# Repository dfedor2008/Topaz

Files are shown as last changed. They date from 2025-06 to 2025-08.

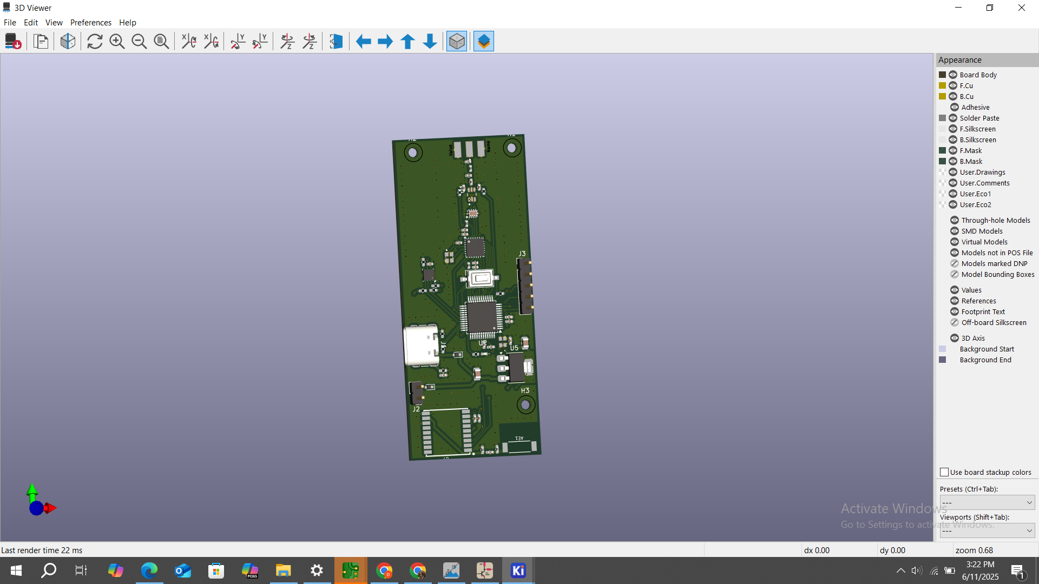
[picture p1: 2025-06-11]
3D_Image.png

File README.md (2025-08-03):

# Topaz - A Lightweight Long-Range GPS Telemetry System

---

## What is Topaz?

Topaz is a compact, cost-effective GPS telemetry platform designed for long-range data transmission using LoRa modulation. It supports both Morse code and binary telemetry formats and integrates environmental sensing, making it suitable for high-altitude ballooning, rocket recovery, remote monitoring, and more.

Topaz In Action

---

## Features & Components

- **Microcontroller** — [ATSAMD21G18A](https://www.microchip.com/en-us/product/atsamd21g18): A reliable, low-power Cortex-M0+ MCU from Microchip.
- **LoRa Radio** — [SX1262](https://www.semtech.com/products/wireless-rf/lora-transceivers/sx1262): Sub-GHz long-range radio for Morse or telemetry data.
- **GPS Receiver** — [ATGM336H](https://jlcpcb.com/partdetail/Zhongkewei-ATGM336H5N31/C90770): Provides position and timing data.
- **Environmental Sensor** — [BME280](https://www.bosch-sensortec.com/products/environmental-sensors/humidity-sensors-bme280/): Measures temperature, humidity, and pressure.
- **Power Supply** — Designed to run from USB or external LiPo/boosted AA battery (3.3V).

---

---

## Use Cases

- Tracker for rockets
- Tracking for general uses
- Environmental monitoring (bme sensor)  

---

## How It Works

1. The **ATGM336H GPS module** gathers location and time.  
2. The **BME280** reads environmental parameters.  
3. The **SAMD21** processes the data.  
4. The **SX1262** transmits the payload via LoRa (in Morse or binary formats).  
5. A paired Topaz device or SDR can receive and decode the transmission.

All firmware is written in **C++**

---

## Hardware Setup Guide

1. **Solder the PCB** — A reflow plate is recommended for clean results.  
2. **Inspect for Shorts** — Pay extra attention around power and MCU pins.  
3. **Power Up via External Supply (not USB)** — Watch for smoke or abnormal heat. Power off immediately if detected.  
4. **Connect via USB** — Once verified safe, plug into your computer.

> After soldering and testing, upload the firmware via Arduino IDE. Topaz is optimized for affordability and robustness.

---

## PCB Diagrams

### Schematic

Topaz Schematic

### Layout

Topaz Layout

---

## Software & Configuration

This project uses the Arduino platform. Libraries include:

- TinyGPS++  
- Adafruit_BME280  
- RadioHead or LoRa drivers for SX1262

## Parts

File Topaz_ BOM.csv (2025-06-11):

null | Sourced | Placed | References | Value | Footprint | Quantity
1 | ✓ | ✓ | C7, C12, C13 | 1nF | C_0402_1005Metric | 3
2 | ✓ | ✓ | C2, C22 | 100nF | C_0402_1005Metric_Pad0.74x0.62mm_HandSolder | 2
3 |  |  | C3, C5 | 100 nF | C_0402_1005Metric_Pad0.74x0.62mm_HandSolder | 2
4 | ✓ | ✓ | C10, C11 | 47pF | C_0402_1005Metric | 2
5 |  |  | C15, C16 | 3.3pF | C_0402_1005Metric | 2
6 | ✓ | ✓ | C17, C18 | 22u | C_0805_2012Metric | 2
7 |  |  | C1 | 1uF | C_0402_1005Metric_Pad0.74x0.62mm_HandSolder | 1
8 |  |  | C4 | 10 uF | C_0402_1005Metric_Pad0.74x0.62mm_HandSolder | 1
9 | ✓ | ✓ | C6 | 4.7 nF | C_0402_1005Metric_Pad0.74x0.62mm_HandSolder | 1
10 |  |  | C8 | 100nF | C_0402_1005Metric | 1
11 | ✓ | ✓ | C9 | 470nF | C_0402_1005Metric | 1
12 | ✓ | ✓ | C14 | 39pF | C_0402_1005Metric | 1
13 | ✓ | ✓ | C19 | 1uF | C_0402_1005Metric | 1
14 | ✓ | ✓ | C20 | 1.5pF | C_0402_1005Metric_Pad0.74x0.62mm_HandSolder | 1
15 | ✓ | ✓ | C21 | 10uF | C_0402_1005Metric_Pad0.74x0.62mm_HandSolder | 1
16 | ✓ | ✓ | R1, R2 | 1.8k | R_0402_1005Metric_Pad0.72x0.64mm_HandSolder | 2
17 | ✓ | ✓ | R5, R6 | 5k1 | R_0402_1005Metric_Pad0.72x0.64mm_HandSolder | 2
18 |  |  | R7, R8 | 10k | R_0402_1005Metric_Pad0.72x0.64mm_HandSolder | 2
19 | ✓ | ✓ | R9, R11 | 100 | R_0402_1005Metric | 2
20 | ✓ | ✓ | R3 | 220 | R_0402_1005Metric_Pad0.72x0.64mm_HandSolder | 1
21 |  |  | R4 | 1M | R_0402_1005Metric_Pad0.72x0.64mm_HandSolder | 1
22 | ✓ | ✓ | R10 | 300 | R_0402_1005Metric | 1
23 | ✓ | ✓ | L4, L5 | 3.9 nH | L_0402_1005Metric_Pad0.77x0.64mm_HandSolder | 2
24 | ✓ | ✓ | L1 | 15uH | L_0402_1005Metric | 1
25 | ✓ | ✓ | L2 | 47nH | L_0402_1005Metric | 1
26 | ✓ | ✓ | L3 | 9.1nH | L_0402_1005Metric | 1
27 |  |  | D1, D2 | 1N4148WT | D_SOD-523 | 2
28 | ✓ | ✓ | D3 | LED | LED_0402_1005Metric | 1
29 | ✓ | ✓ | U1 | PE4259 | PE4259 | 1
30 | ✓ | ✓ | U2 | ATSAMD21G18A-A | TQFP-48_7x7mm_P0.5mm | 1
31 | ✓ | ✓ | U3 | ECS-327TXO-2012 | OSC_ECS-327TXO-2012-33-TR | 1
32 | ✓ | ✓ | U4 | SX1262IMLTRT | QFN-24-1EP_4x4mm_P0.5mm_EP2.6x2.6mm | 1
33 |  |  | U5 | AMS1117-3.3 | SOT-223-3_TabPin2 | 1
34 | ✓ | ✓ | U6 | BME280 | Bosch_LGA-8_2.5x2.5mm_P0.65mm_ClockwisePinNumbering | 1
35 | ✓ | ✓ | U7 | ATGM336H | ATGM336H | 1
36 | ✓ | ✓ | Y1 | FA-128_32.0000MF20X-K5 | OSCCC200X160X50 | 1
37 | ✓ | ✓ | SW1 | RST | SW_Tactile_SPST_NO_Straight_CK_PTS636Sx25SMTRLFS | 1
38 | ✓ | ✓ | AE1 | 1575AT43A0040 | 609-1575AT43A0040E | 1
39 | ✓ | ✓ | FL1 | 0900FM15K0039 | Balun_Johanson_0900FM15K0039 | 1
40 | ✓ | ✓ | Je2 | Conn_Coaxial | RFSOLUTIONS_CON-SMA-EDGE-S | 1
41 | ✓ | ✓ | J1 | USBC | USB_C_Receptacle_GCT_USB4105-xx-A_16P_TopMnt_Horizontal | 1
42 |  |  | J2 | POWER IN | PinHeader_1x02_P2.54mm_Vertical | 1
43 | ✓ | ✓ | J3 | ~ | PinHeader_1x05_P2.54mm_Vertical | 1

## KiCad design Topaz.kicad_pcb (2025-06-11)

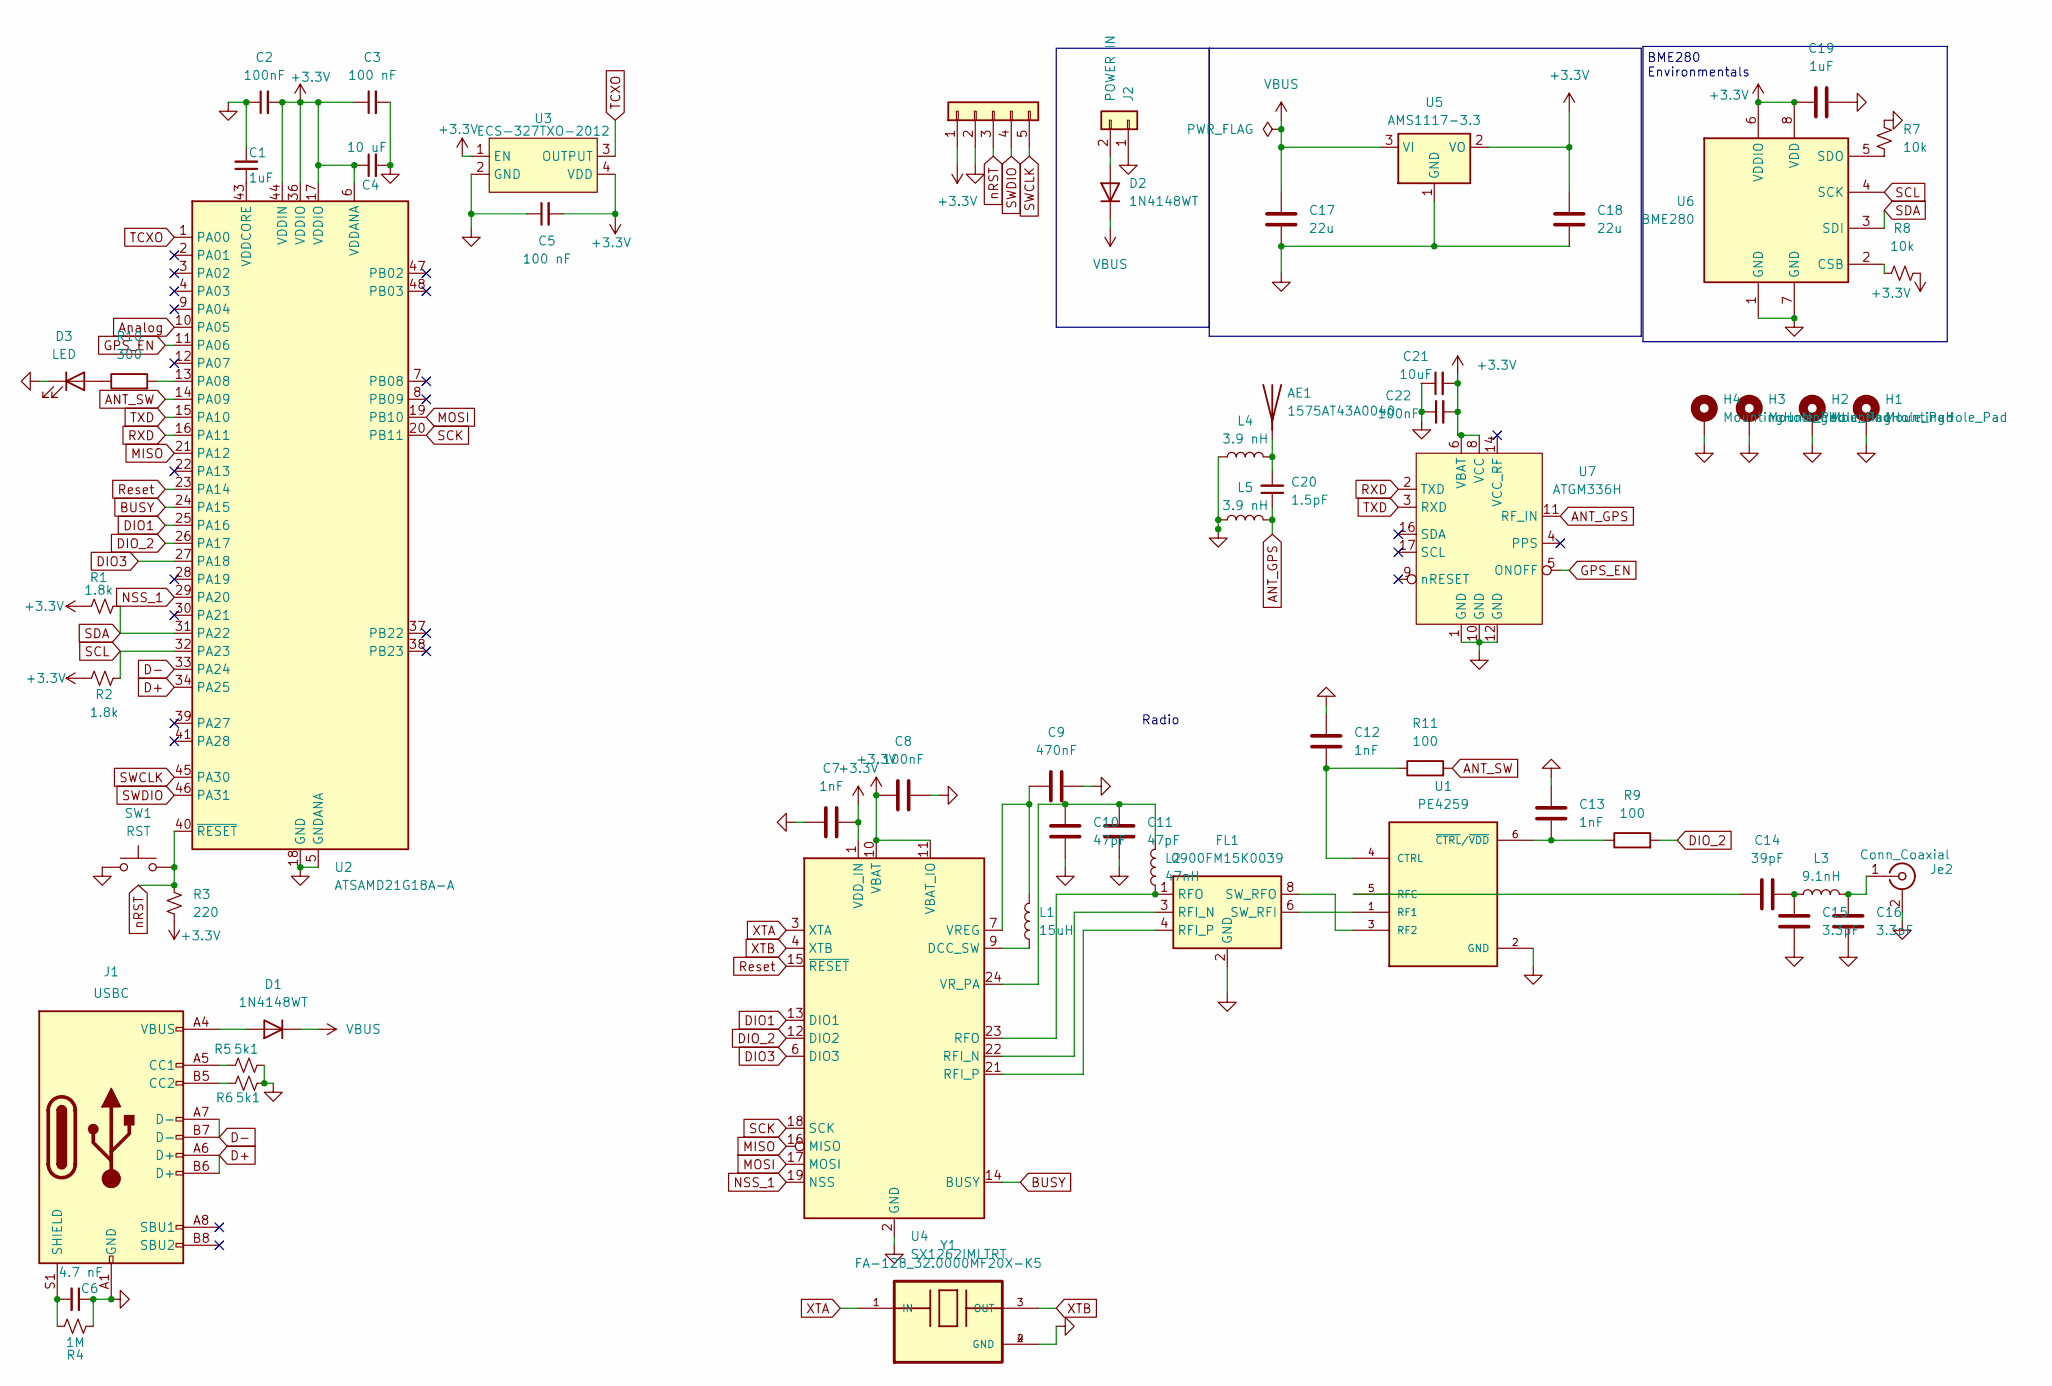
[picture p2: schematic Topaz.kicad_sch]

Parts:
AE1: 1575AT43A0040; 609-1575AT43A0040E; LCSC C239243
C1: 1uF; C_0402_1005Metric_Pad0.74x0.62mm_HandSolder; LCSC C52923
C2, C22: 100nF; C_0402_1005Metric_Pad0.74x0.62mm_HandSolder; LCSC C1525
C3, C5: 100 nF; C_0402_1005Metric_Pad0.74x0.62mm_HandSolder; LCSC C1525
C4: 10 uF; C_0402_1005Metric_Pad0.74x0.62mm_HandSolder; LCSC C19702
C6: 4.7 nF; C_0402_1005Metric_Pad0.74x0.62mm_HandSolder; LCSC C1744
C7, C12, C13: 1nF; C_0402_1005Metric
C8: 100nF; C_0402_1005Metric
C9: 470nF; C_0402_1005Metric
C10, C11: 47pF; C_0402_1005Metric
C14: 39pF; C_0402_1005Metric
C15, C16: 3.3pF; C_0402_1005Metric
C17, C18: 22u; C_0805_2012Metric
C19: 1uF; C_0402_1005Metric
C20: 1.5pF; C_0402_1005Metric_Pad0.74x0.62mm_HandSolder; LCSC C1525
C21: 10uF; C_0402_1005Metric_Pad0.74x0.62mm_HandSolder; LCSC C19702
D1, D2: 1N4148WT; D_SOD-523
D3: LED; LED_0402_1005Metric
FL1: 0900FM15K0039; Balun_Johanson_0900FM15K0039
H1, H2, H3, H4: MountingHole_Pad; MountingHole_2.1mm
J1: USBC; USB_C_Receptacle_GCT_USB4105-xx-A_16P_TopMnt_Horizontal; LCSC C136423
J2: POWER IN; PinHeader_1x02_P2.54mm_Vertical
J3: PinHeader_1x05_P2.54mm_Vertical
Je2: Conn_Coaxial; RFSOLUTIONS_CON-SMA-EDGE-S
L1: 15uH; L_0402_1005Metric
L2: 47nH; L_0402_1005Metric
L3: 9.1nH; L_0402_1005Metric
L4, L5: 3.9 nH; L_0402_1005Metric_Pad0.77x0.64mm_HandSolder; LCSC C307609
R1, R2: 1.8k; R_0402_1005Metric_Pad0.72x0.64mm_HandSolder; LCSC C4177
R3: 220; R_0402_1005Metric_Pad0.72x0.64mm_HandSolder; LCSC C25091
R4: 1M; R_0402_1005Metric_Pad0.72x0.64mm_HandSolder; LCSC C26083
R5, R6: 5k1; R_0402_1005Metric_Pad0.72x0.64mm_HandSolder; LCSC C27834
R7, R8: 10k; R_0402_1005Metric_Pad0.72x0.64mm_HandSolder; LCSC C25744
R9, R11: 100; R_0402_1005Metric
R10: 300; R_0402_1005Metric
SW1: RST; SW_Tactile_SPST_NO_Straight_CK_PTS636Sx25SMTRLFS; LCSC C2888954
U1: PE4259
U2: ATSAMD21G18A-A; TQFP-48_7x7mm_P0.5mm; LCSC C78624
U3: ECS-327TXO-2012; OSC_ECS-327TXO-2012-33-TR; LCSC C213398
U4: SX1262IMLTRT; QFN-24-1EP_4x4mm_P0.5mm_EP2.6x2.6mm
U5: AMS1117-3.3; SOT-223-3_TabPin2
U6: BME280; Bosch_LGA-8_2.5x2.5mm_P0.65mm_ClockwisePinNumbering
U7: ATGM336H; LCSC C5117921
Y1: FA-128_32.0000MF20X-K5; OSCCC200X160X50

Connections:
+3.3V: C2.2, C3.1, C4.1, C5.2, C7.2, C8.1, C18.1, C19.1, C21.2, C22.2, J3.1, R1.2, R2.1, R3.2, R8.1, U2.6 (VDDANA), U2.17 (VDDIO), U2.36 (VDDIO), U2.44 (VDDIN), U3.1 (EN), U3.4 (VDD), U4.1 (VDD_IN), U4.10 (VBAT), U4.11 (VBAT_IO), U5.2 (VO), U6.6 (VDDIO), U6.8 (VDD), U7.6 (VBAT), U7.8 (VCC)
ANT_GPS: C20.1, L5.2, U7.11 (RF_IN)
ANT_SW: R11.2, U2.14 (PA09)
Analog: U2.10 (PA05)
BUSY: U2.24 (PA15), U4.14 (BUSY)
D+: J1.A6 (D+), J1.B6 (D+), U2.34 (PA25)
D-: J1.A7 (D-), J1.B7 (D-), U2.33 (PA24)
DIO1: U2.25 (PA16), U4.13 (DIO1)
DIO3: U2.27 (PA18), U4.6 (DIO3)
DIO_2: R9.2, U2.26 (PA17), U4.12 (DIO2)
GND: C1.2, C2.1, C3.2, C4.2, C5.1, C6.1, C7.1, C8.2, C9.2, C10.1, C11.1, C12.1, C13.1, C15.2, C16.2, C17.2, C18.2, C19.2, C21.1, C22.1, D3.1 (K), FL1.2 (GND), FL1.5 (GND), FL1.7 (GND), FL1.9 (GND), FL1.10 (GND), H1.1, H2.1, H3.1, H4.1, J1.A1 (GND), J1.A12 (GND), J1.B1 (GND), J1.B12 (GND), J2.1, J3.2, Je2.1 (In), Je2.2 (Ext), L4.1, L5.1, R4.2, R5.1, R6.1, R7.2, SW1.1, U1.2 (GND), U2.5 (GNDANA), U2.18 (GND), U2.35 (GND), U2.42 (GND), U3.2 (GND), U4.2 (GND), U4.5 (GND), U4.8 (GND), U4.20 (GND), U4.25 (GND), U5.1 (GND), U6.1 (GND), U6.7 (GND), U7.1 (GND), U7.10 (GND), U7.12 (GND), Y1.2 (GND), Y1.4 (GND)
GPS_EN: U2.11 (PA06), U7.5 (ONOFF)
MISO: U2.21 (PA12), U4.16 (MISO)
MOSI: U2.19 (PB10), U4.17 (MOSI)
NSS_1: U2.29 (PA20), U4.19 (NSS)
unnamed: AE1.1 (A), C20.2, L4.2
unnamed: C14.2, C15.1, L3.1
unnamed: D1.2 (A), J1.A4 (VBUS), J1.A9 (VBUS), J1.B4 (VBUS), J1.B9 (VBUS)
unnamed: D2.2 (A), J2.2
unnamed: D3.2 (A), R10.1
unnamed: FL1.3 (RFI_N), U4.22 (RFI_N)
unnamed: FL1.4 (RFI_P), U4.21 (RFI_P)
unnamed: FL1.1 (RFO), L2.1, U4.23 (RFO)
unnamed: FL1.6 (SW_RFI), U1.1 (RF1)
unnamed: FL1.8 (SW_RFO), U1.3 (RF2)
unnamed: J1.A5 (CC1), R5.2
unnamed: J1.B5 (CC2), R6.2
unnamed: C6.2, J1.S1 (SHIELD), R4.1
unnamed: C16.1, Je2.1 (In), L3.2
unnamed: C12.2, R11.1, U1.4 (CTRL)
unnamed: C14.1, U1.5 (RFC)
unnamed: C13.2, R9.1, U1.6 (~CTRL/~VDD)
unnamed: R10.2, U2.13 (PA08)
unnamed: C1.1, U2.43 (VDDCORE)
unnamed: L1.1, U4.9 (DCC_SW)
unnamed: C9.1, L1.2, U4.7 (VREG)
unnamed: C10.2, C11.2, L2.2, U4.24 (VR_PA)
unnamed: R8.2, U6.2 (CSB)
unnamed: R7.1, U6.5 (SDO)
RXD: U2.16 (PA11), U7.2 (TXD)
Reset: U2.23 (PA14), U4.15 (~RESET)
SCK: U2.20 (PB11), U4.18 (SCK)
SCL: R2.2, U2.32 (PA23), U6.4 (SCK)
SDA: R1.1, U2.31 (PA22), U6.3 (SDI)
SWCLK: J3.5, U2.45 (PA30)
SWDIO: J3.4, U2.46 (PA31)
TCXO: U2.1 (PA00), U3.3 (OUTPUT)
TXD: U2.15 (PA10), U7.3 (RXD)
VBUS: C17.1, D1.1 (K), D2.1 (K), U5.3 (VI)
XTA: U4.3 (XTA), Y1.1 (IN)
XTB: U4.4 (XTB), Y1.3 (OUT)
nRST: J3.3, R3.1, SW1.2, U2.40 (~RESET)

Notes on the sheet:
BME280 Environmentals
Radio

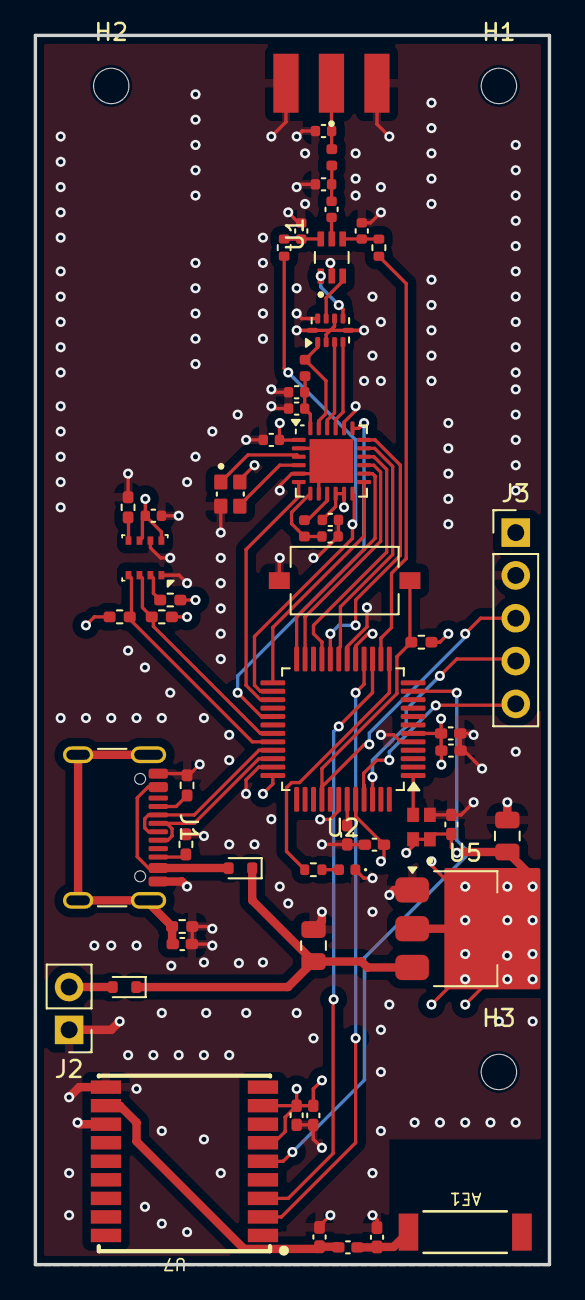
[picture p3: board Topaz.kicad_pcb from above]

Board: 4 copper layers, 30.5 x 72.9 mm, 60 parts (0 on the bottom side), 51 nets.

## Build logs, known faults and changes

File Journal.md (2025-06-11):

---
title: "Topaz"
author: "Dawid Fedor"
description: "Radio module which can pressure, temperature and humitidy, and location"
created_at: "2025-05-27"
---
Total time: 9.5h
Day 1:
Today I worked on the schematic. I decided to use a SAMD21, an SX1262, and a BME280, as I have previous experience with them. I imported custom parts from Snap EDA and modified the (PE4257, and ESC32TXO).
Time spent:~2 hours


Day 2:
The schematic is finished. I moved on to the PCB layout. I imported a custom oscillator (ECS-327TXO-2012) for the SAMD21. I'm quite happy with the design so far.
I also revisited the schematic and added another button, which could potentially be used for Morse code input in the future.
Time spent:~3 hours

Day 3:
I changed the minimum track spacing to 0.127 mm to prevent copper pads from merging, in line with OSH Park’s manufacturing limits.
I also worked on minimizing the PCB size to help reduce production costs.
Time spent:~2.5 hours

Day 4:
Final changes were added. Fixed certain errors in DRC. Fixed final arragment problems. I went back to KiCad and ran ERC to checked and fixed any errors.
I reviewed for a final time the schematic to see if I missed anything ( compared it with the manufactorers reference design and datasheets). 
Time spent: 2 hours


Day 5:
I added a GPS module so that location can be transmitted. I added a ATGM336H with a passive antenna. I chose this module because it is a very cheap and affordable.

Time spent: 2 hours

Overall Notes:
The biggest challenge I faced was figuring out the RF section. The manufacturer-recommended RF switch, the BGS12WN6E6327, is extremely small and nearly impossible to solder by hand.
To resolve this, I decided to find a replacement and settled on the PE4259, which is considerably larger and easier to solder.

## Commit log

2025-06-08 Gerber files
    [Topaz-B_Cu.gbl, Topaz-B_Mask.gbs, Topaz-B_Paste.gbp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]
2025-06-11 Rename Topaz (2).csv to Topaz_ BOM.csv
    [Topaz_ BOM.csv]
